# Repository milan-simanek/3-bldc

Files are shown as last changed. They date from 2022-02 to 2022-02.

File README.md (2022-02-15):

# 3-bldc
3-phase brushless DC motor controller

## Features:
- controls 3-phase BLDC motor
- synchronization using opto-sensors

## Arduino peripherals usage:
- Timer0 - PWM
- Timer1 - generic timer, phase detection
- PB0:5 - phase output
    - PB0: phase 1 - high
    - PB1: phase 2 - high
    - PB2: phase 3 - high
    - PB3: phase 1 - low
    - PB4: phase 2 - low
    - PB5: phase 3 - low
- PC0/PCINT8 - ~FAULT - overcurrent detection
- PC3/ADC3 - output current measurement
- PD0:1 - serial communication
- PD2/INT0 = (zero angle = home position) detection (triggered by both edges)
- PD3/INT1 = step sensor A
- PD4 = step sensor B
- PD5 = OC0B = PWM output

## Issues:
- opto-sensor feedback is currently amplified by operating amplifiers.
  Unfortunately, these devices should operate on higher voltage, so 
  amplification is not so stable and produces flicking.
  Solution: signal from opto-sensors should be amplified and
  conditioned by CMOS invertor based schmitt trigger.

## TODO:
- rotation feedback could be derived from back-EMF.
- maximum speed, acceleration measurements
- use avrm modules for usart communication and text formating (comf)

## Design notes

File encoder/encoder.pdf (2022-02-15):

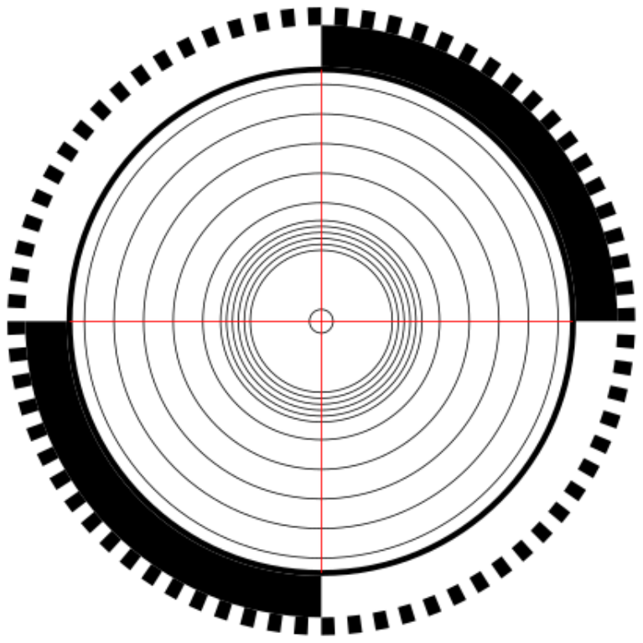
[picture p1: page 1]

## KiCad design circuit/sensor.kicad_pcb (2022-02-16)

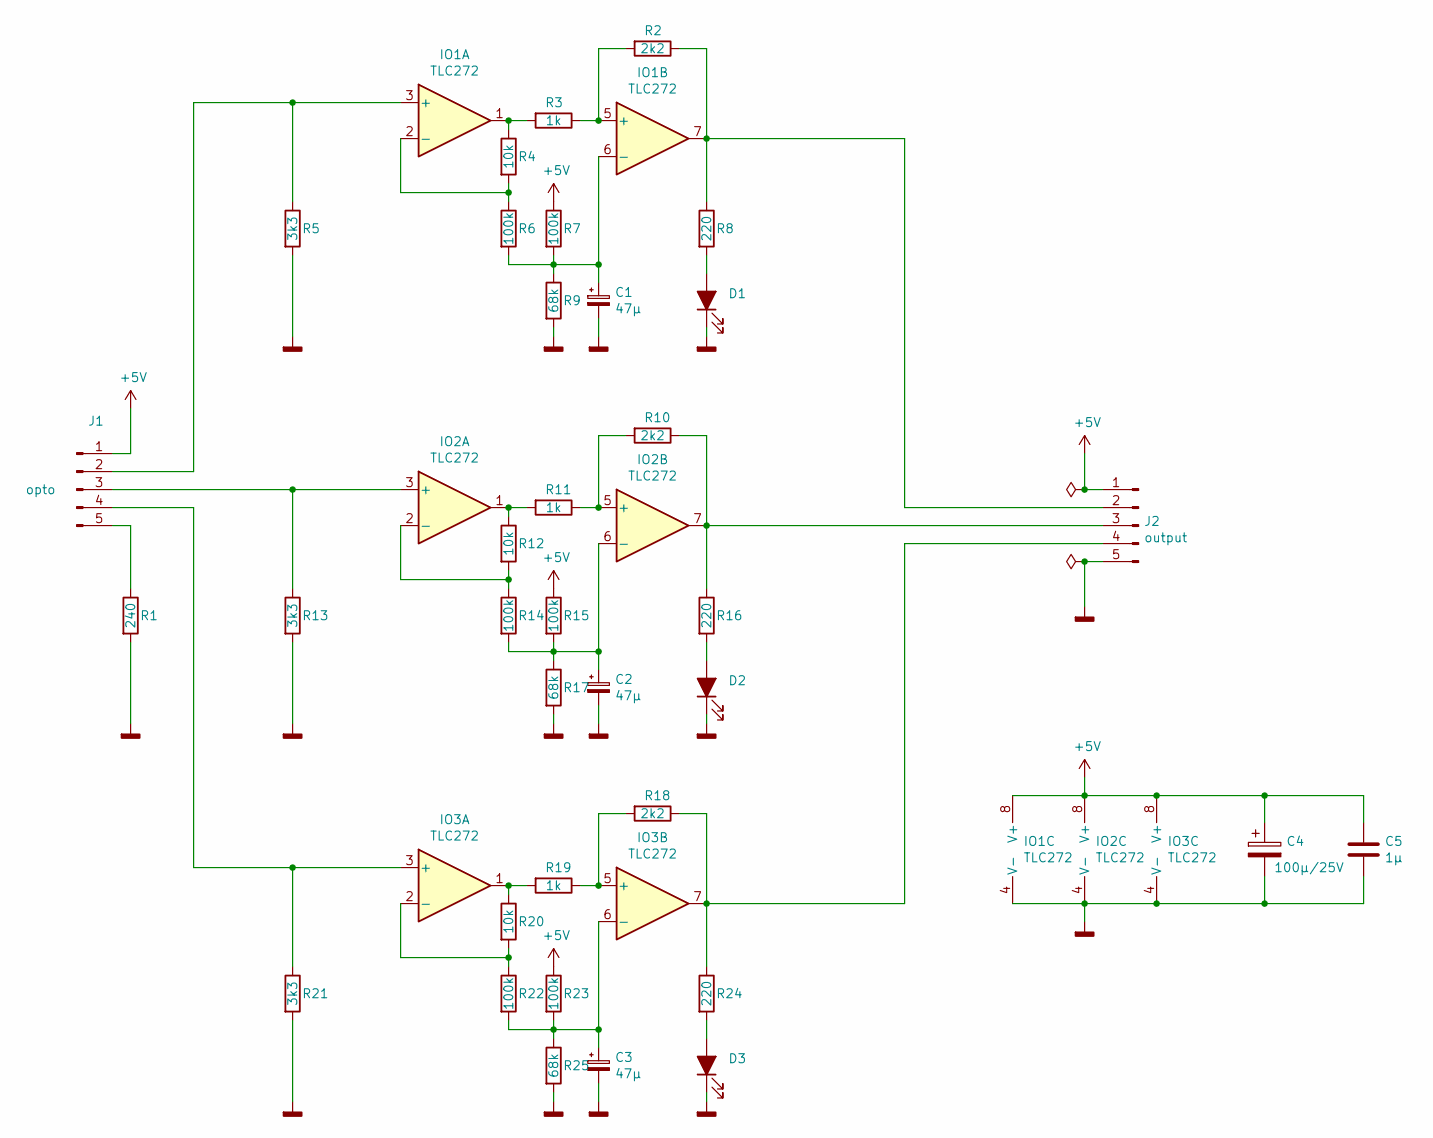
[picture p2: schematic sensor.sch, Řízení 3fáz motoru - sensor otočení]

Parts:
C1, C2, C3: 47μ; CP_Radial_D5.0mm_P2.50mm
C4: 100μ/25V; CP_Radial_D6.3mm_P2.50mm
C5: 1μ; C_Rect_L16.5mm_W4.7mm_P15.00mm_MKT
D1, D2, D3: LED_ALT; LED_D3.0mm
IO1, IO2, IO3: TLC272; DIP-8_W7.62mm_LongPads
J1: opto; PinHeader_1x05_P2.54mm_Vertical
J2: output; PinHeader_1x05_P2.54mm_Vertical
R1: 240; R_Axial_DIN0207_L6.3mm_D2.5mm_P10.16mm_Horizontal
R2, R10, R18: 2k2; R_Axial_DIN0207_L6.3mm_D2.5mm_P10.16mm_Horizontal
R3, R11, R19: 1k; R_Axial_DIN0207_L6.3mm_D2.5mm_P10.16mm_Horizontal
R4, R12, R20: 10k; R_Axial_DIN0207_L6.3mm_D2.5mm_P10.16mm_Horizontal
R5, R13, R21: 3k3; R_Axial_DIN0207_L6.3mm_D2.5mm_P10.16mm_Horizontal
R6, R7, R14, R15, R22, R23: 100k; R_Axial_DIN0207_L6.3mm_D2.5mm_P10.16mm_Horizontal
R8, R16, R24: 220; R_Axial_DIN0207_L6.3mm_D2.5mm_P10.16mm_Horizontal
R9, R17, R25: 68k; R_Axial_DIN0207_L6.3mm_D2.5mm_P10.16mm_Horizontal

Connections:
+5V: C4.1, C5.1, IO1.8 (V+), IO2.8 (V+), IO3.8 (V+), J1.1, J2.1, R7.1, R15.1, R23.1
GNDD: C1.2, C2.2, C3.2, C4.2, C5.2, D1.1 (K), D2.1 (K), D3.1 (K), IO1.4 (V-), IO2.4 (V-), IO3.4 (V-), J2.5, R1.2, R5.2, R9.2, R13.2, R17.2, R21.2, R25.2
unnamed: C1.1, IO1.6 (-), R6.2, R7.2, R9.1
unnamed: C2.1, IO2.6 (-), R14.2, R15.2, R17.1
unnamed: C3.1, IO3.6 (-), R22.2, R23.2, R25.1
unnamed: D1.2 (A), R8.2
unnamed: D2.2 (A), R16.2
unnamed: D3.2 (A), R24.2
unnamed: IO1.1, R3.2, R4.1
unnamed: IO1.2 (-), R4.2, R6.1
unnamed: IO1.3 (+), J1.2, R5.1
unnamed: IO1.5 (+), R2.2, R3.1
unnamed: IO1.7, J2.2, R2.1, R8.1
unnamed: IO2.1, R11.2, R12.1
unnamed: IO2.2 (-), R12.2, R14.1
unnamed: IO2.3 (+), J1.3, R13.1
unnamed: IO2.5 (+), R10.2, R11.1
unnamed: IO2.7, J2.3, R10.1, R16.1
unnamed: IO3.1, R19.2, R20.1
unnamed: IO3.2 (-), R20.2, R22.1
unnamed: IO3.3 (+), J1.4, R21.1
unnamed: IO3.5 (+), R18.2, R19.1
unnamed: IO3.7, J2.4, R18.1, R24.1
unnamed: J1.5, R1.1

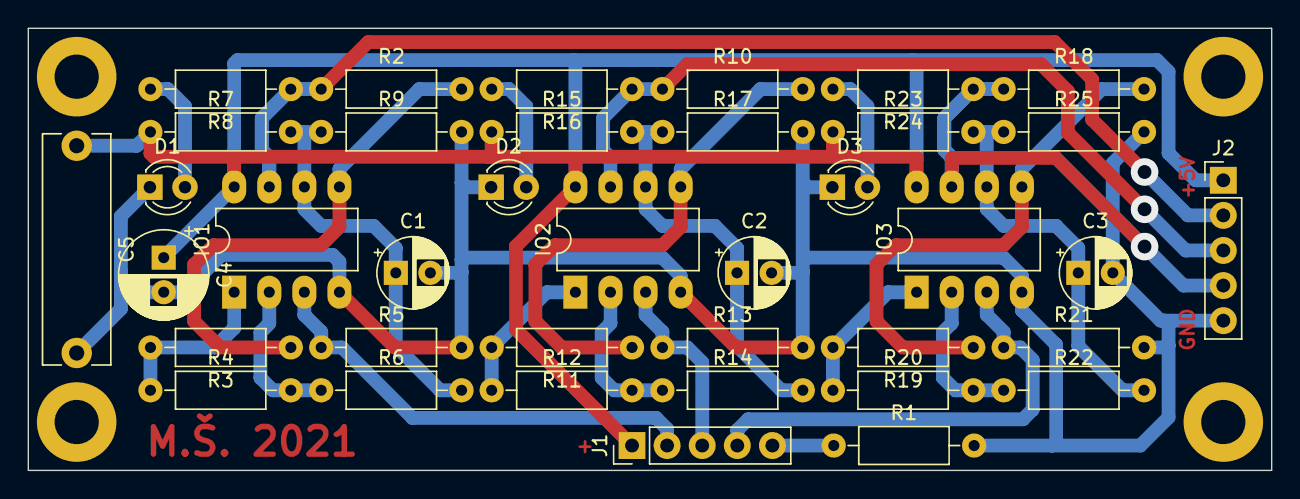
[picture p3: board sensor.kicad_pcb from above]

Board: 2 copper layers, 90.0 x 32.0 mm, 38 parts (0 on the bottom side), 24 nets.

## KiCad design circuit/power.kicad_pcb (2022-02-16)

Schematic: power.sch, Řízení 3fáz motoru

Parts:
C1: 15n; C_Rect_L4.6mm_W2.0mm_P2.50mm_MKS02_FKP02
C2, C4, C9: 330n; C213_L16_W7.5_P12.5
C3: 22μ; CP_Axial_L18.0mm_D6.5mm_P25.00mm_Horizontal
C5, C6, C7: 4μ7; CP_Radial_Tantal_D4.5mm_P2.50mm
C8: 1000μ/16V; CP_Radial_D10.0mm_P5.00mm
D1: error; LED_D5.0mm
D2, D3, D4, D5, D6, D7, D8, D9, D10: 1N4937; D_DO-41_SOD81_P10.16mm_Horizontal
IO1: CD4071; DIP-14_W7.62mm_LongPads
IO2: IR2130; DIP-28_W15.24mm_LongPads
J1: control; PinHeader_1x12_P2.54mm_Vertical
J2: test; PinHeader_1x06_P2.54mm_Vertical
J3: test; PinHeader_1x05_P2.54mm_Vertical
J4: power; BarrelJack_Horizontal
J5: power12; PinHeader_1x02_P2.54mm_Vertical
J6: motor; PinHeader_1x04_P2.54mm_Vertical
J7: msensor; PinHeader_1x04_P2.54mm_Vertical
P1: 680; Potentiometer_ACP_CA9-H5_Horizontal
P2: 220; Potentiometer_ACP_CA9-H5_Horizontal
R1, R2: 15k; R_Axial_DIN0207_L6.3mm_D2.5mm_P10.16mm_Horizontal
R3: 100k; R_Axial_DIN0207_L6.3mm_D2.5mm_P10.16mm_Horizontal
R4, R8: 1k; R_Axial_DIN0207_L6.3mm_D2.5mm_P10.16mm_Horizontal
R5: 10k; R_Axial_DIN0207_L6.3mm_D2.5mm_P10.16mm_Horizontal
R6: 0.5Ω/5W; R_Axial_Power_L25.0mm_W9.0mm_P30.48mm
R7: 220; R_Axial_DIN0207_L6.3mm_D2.5mm_P10.16mm_Horizontal
R9: 100; R_Axial_DIN0207_L6.3mm_D2.5mm_P10.16mm_Horizontal
R10, R11, R12, R13, R14, R15: 18; R_Axial_DIN0207_L6.3mm_D2.5mm_P10.16mm_Horizontal
T1: BSS83P; SOT-23
T2, T3, T4, T5, T6, T7: BUZ11; TO-220-3_Vertical
TL1: STOP; Tlacitko_hranate

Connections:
+5V: C2.1, C3.1, IO1.14, J1.2, R5.2, T1.3, TL1.2, TL1.3, TL1.5, TL1.6
+12V: C4.1, C8.1, C9.1, D5.1, D7.1, D9.1, IO2.1, J1.1, J4.1, J5.2, R9.1, T2.2, T4.2, T6.2
/CAO: IO2.10, J1.11, J3.3, R2.2, R3.2
/GNDPWR: C9.2, D6.2, D8.2, D10.2, IO2.13, R6.2, R8.1, T3.3, T5.3, T7.3
/L1: C5.2, D5.2, D6.1, IO2.26, J6.2, J7.2, T2.3, T3.2
/L2: C6.2, D7.2, D8.1, IO2.22, J6.3, J7.3, T4.3, T5.2
/L3: C7.2, D9.2, D10.1, IO2.18, J6.4, J7.4, T6.3, T7.2
/stop: C1.1, IO1.8, R1.2, TL1.1, TL1.4
/~FAULT: IO2.8, J1.10, J3.1, R5.1, T1.1
GNDD: C1.2, C2.2, C3.2, C4.2, C8.2, IO1.7, IO2.12, J1.12, J3.5, J4.2, J5.1, P1.3, P2.1, R1.1, R4.1, R6.1, R7.1
unnamed: C5.1, D2.1, IO2.28
unnamed: C6.1, D3.1, IO2.24
unnamed: C7.1, D4.1, IO2.20
unnamed: D1.1 (K), R7.2
unnamed: D1.2 (A), T1.2
unnamed: D2.2, D3.2, D4.2, R9.2
unnamed: IO1.1, J1.5
unnamed: IO1.3, IO2.3, J2.2
unnamed: IO1.4, IO2.4, J2.3
unnamed: IO1.6, J1.6
unnamed: IO1.9, J1.3
unnamed: IO1.2, IO1.5, IO1.10, IO1.12
unnamed: IO1.11, IO2.2, J2.1
unnamed: IO1.13, J1.4
unnamed: IO2.5, J1.7, J2.4
unnamed: IO2.6, J1.8, J2.5
unnamed: IO2.7, J1.9, J2.6
unnamed: IO2.9, J3.2, P2.2
unnamed: IO2.11, J3.4, P1.2, R3.1, R4.2
unnamed: IO2.14, R15.2
unnamed: IO2.15, R14.2
unnamed: IO2.16, R13.2
unnamed: IO2.19, R12.2
unnamed: IO2.23, R11.2
unnamed: IO2.27, R10.2
unnamed: J6.1, J7.1
unnamed: P1.1, R2.1
unnamed: P2.3, R8.2
unnamed: R10.1, T2.1
unnamed: R11.1, T4.1
unnamed: R12.1, T6.1
unnamed: R13.1, T3.1
unnamed: R14.1, T5.1
unnamed: R15.1, T7.1

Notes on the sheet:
12V DC

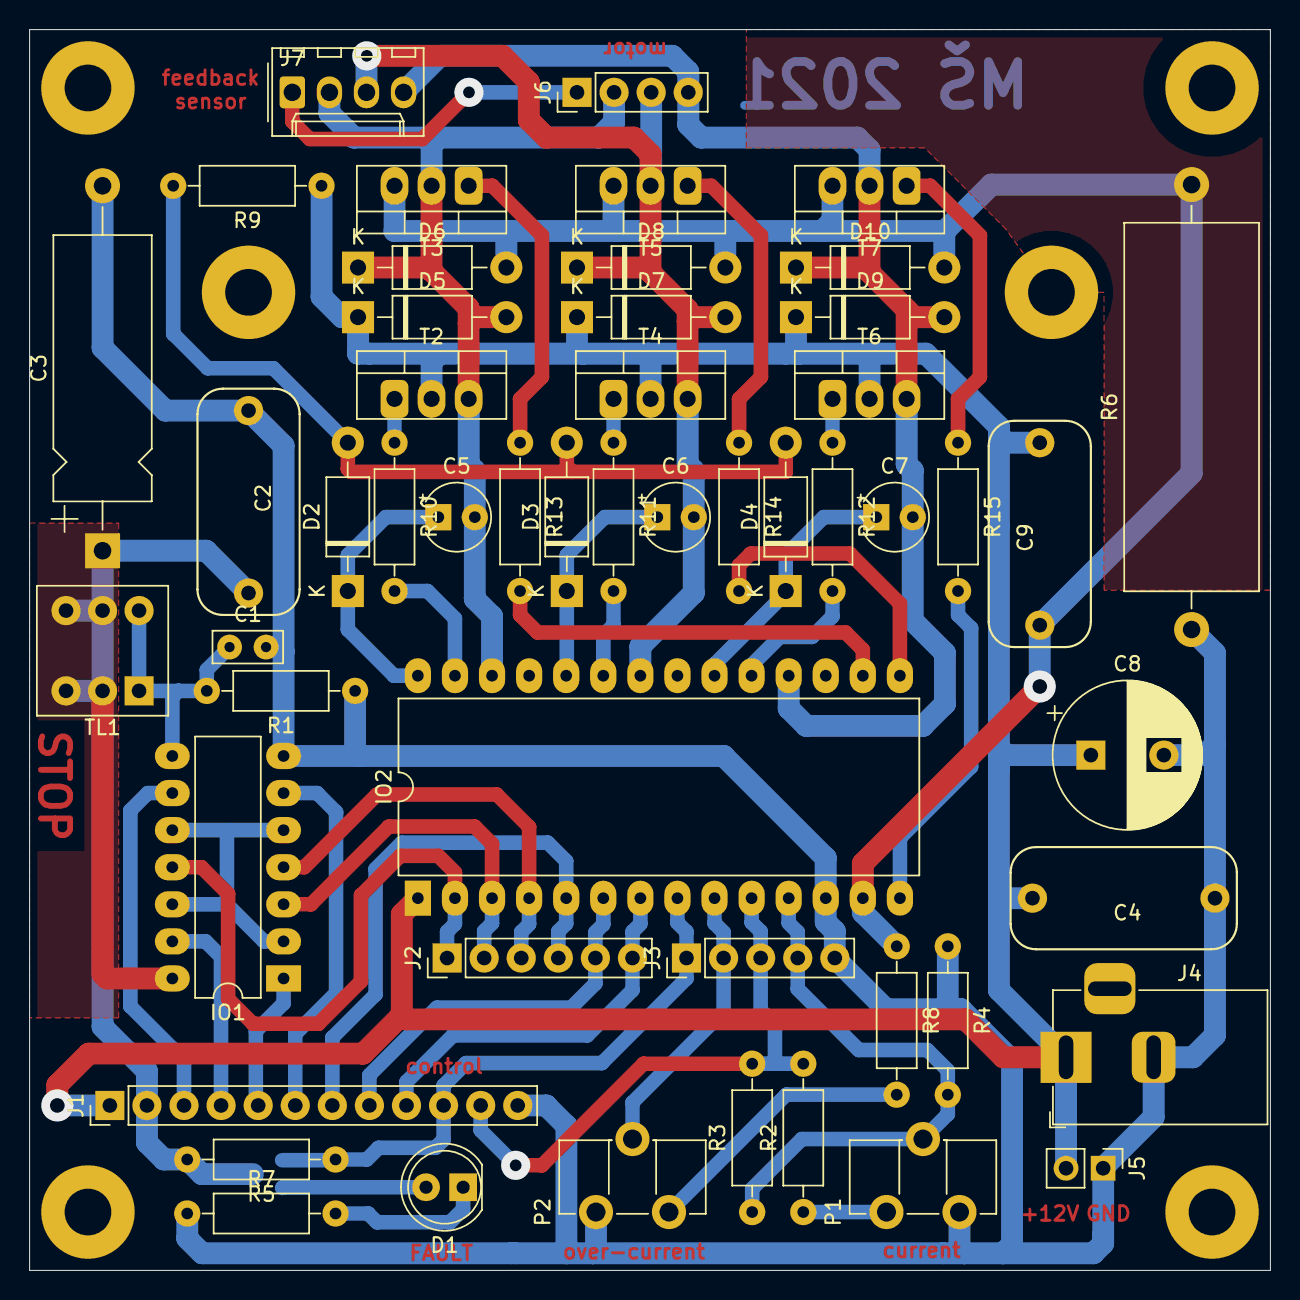
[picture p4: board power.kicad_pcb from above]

Board: 2 copper layers, 85.0 x 85.0 mm, 53 parts (1 on the bottom side), 44 nets.

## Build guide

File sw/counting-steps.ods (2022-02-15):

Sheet: steps36
SENSORSTEPS |  | 36
 |  | counting up |  | counting down
step | PosFrac8 | F(n+1)-F(n) | (F(n)+7)&0x3F==0x3F | F(n)-F(n-1) | F(n)&0x3F==0
0 | 0 | 7 | 0 |  | 1
1 | 7 | 7 | 0 | 7 | 0
2 | 14 | 7 | 0 | 7 | 0
3 | 21 | 7 | 0 | 7 | 0
4 | 28 | 7 | 0 | 7 | 0
5 | 35 | 7 | 0 | 7 | 0
6 | 42 | 7 | 0 | 7 | 0
7 | 49 | 7 | 0 | 7 | 0
8 | 56 | 8 | 1 | 7 | 0
9 | 64 | 7 | 0 | 8 | 1
10 | 71 | 7 | 0 | 7 | 0
11 | 78 | 7 | 0 | 7 | 0
12 | 85 | 7 | 0 | 7 | 0
13 | 92 | 7 | 0 | 7 | 0
14 | 99 | 7 | 0 | 7 | 0
15 | 106 | 7 | 0 | 7 | 0
16 | 113 | 7 | 0 | 7 | 0
17 | 120 | 8 | 1 | 7 | 0
18 | 128 | 7 | 0 | 8 | 1
19 | 135 | 7 | 0 | 7 | 0
20 | 142 | 7 | 0 | 7 | 0
21 | 149 | 7 | 0 | 7 | 0
22 | 156 | 7 | 0 | 7 | 0
23 | 163 | 7 | 0 | 7 | 0
24 | 170 | 7 | 0 | 7 | 0
25 | 177 | 7 | 0 | 7 | 0
26 | 184 | 8 | 1 | 7 | 0
27 | 192 | 7 | 0 | 8 | 1
28 | 199 | 7 | 0 | 7 | 0
29 | 206 | 7 | 0 | 7 | 0
30 | 213 | 7 | 0 | 7 | 0
31 | 220 | 7 | 0 | 7 | 0
32 | 227 | 7 | 0 | 7 | 0
33 | 234 | 7 | 0 | 7 | 0
34 | 241 | 7 | 0 | 7 | 0
35 | 248 | 8 | 1 | 7 | 0
 | 256 |  |  | 8 | 1
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

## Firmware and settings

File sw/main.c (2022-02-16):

#include "globals.h"
#include <avr/io.h>
#include <avr/interrupt.h>
#include <avr/sleep.h>
#include <avr/pgmspace.h>
#include "main.h"
#include "libclk.h"
#include "passive-wait.h"
#include "com.h"
#include "proto.h"
#include "pwm.h"
#include "const.h"
#include "rot.h"
#include "sensor.h" 
#include "tick.h"
#include "ledkey.h"
#include "ports.h"
#include "macro_ports.h"
#include "usart.h"
#include "comf.h"

char dbgf=1; // debug flag


/**********************************************/

#define MS_OTACEK	6
const char M_MS0[]	PROGMEM = "Measure: \r";
const char M_MS1[]	PROGMEM = "MS: motor off\r";
const char M_MS2[]	PROGMEM = "MS: go to angle 0\r";
const char M_MS_S[]	PROGMEM = "MS: initialization round phase=%\r";
const char M_MS_M[]	PROGMEM = "MS: ph=% pos=% ph-pos=% total=% t_val=%\r";
const char M_MS_E[]	PROGMEM = "MS: end. Sensor=%\r";

// measures the location of zero_angle sensor
unsigned ms_timer;
void MeasureSensor(void) {
  ComFormat(M_MS0);
  SensorDetecting=1;
  ms_timer=3 MST_SECOND;
}
uchar NextPhasePF8(uchar pf8) {
  for(unsigned i=PHASESTEPS;i--;) { StepPlus(pf8); }
  return pf8;
}
  
void MeasureSensorNext(void) {
  static uchar ph;
  static unsigned t_val;
  static int16_t result;
  static uchar curPF8;
  uchar x;
  switch (SensorDetecting++) {
  case 1:			// stop motor
    ComFormat(M_MS1);
    result=0;
    SensorOffset8=0;
    StopMotor();
    ms_timer=1 MST_SECOND;
    break;
  case 2:			// rotate to phase 0 0
    ComFormat(M_MS2);
    OutPhase(ph=0); curPF8=0;
    SetPWM(64);
    ms_timer=1 MST_SECOND;
    break;
  case 3: case 4: case 5: case 6: case 7: case 8: // rotate one round to trigger the sensor
    if (++ph>5) ph=0; 
    curPF8=NextPhasePF8(curPF8);
    OutPhase(ph);
    ComFormat(M_MS_S); ComFHex2(ph);
    ms_timer=10 MST_100MS;
    t_val=10 MST_100MS;
    break;
//  case 9-26: 			// angle measurement
  case MS_OTACEK*6+9:		// finish measurement
    StopMotor();
    result/=(MS_OTACEK*6);
    while (result>0) {		// SensorOffset8=-result;
      StepMinus(result);
      StepMinus(SensorOffset8);
    }
    ComFormat(M_MS_E); ComFHex4(SensorOffset8);
    SensorDetecting=0;
    SetPWM(0);
    break;    
  default: 			// measure each step
    x=PosFract8-curPF8;
    result+=x;
    ComFormat(M_MS_M); ComFHex2(ph); ComFHex2(PosFract8); ComFHex2(x); ComFHex4(result); ComFHex4(t_val);
    ms_timer=t_val;
    t_val-=t_val>>4; 		// speed up
    if (++ph>5) ph=0; 
    curPF8=NextPhasePF8(curPF8);
    OutPhase(ph);
  }
}

void TimeTick(void) {
  static uchar report;
  if (SensorDetecting) if (!--ms_timer) MeasureSensorNext();
  if (!SensorDetecting && (dbgf&1) && !--report) {
    Report();
    report=3 MST_100MS;
  }
}

const char M_Ready[]          PROGMEM = "=== READY ===\r";

int main(void) {
  InitCLK();
  PortsInit();
  LedkeyInit();  
  MotorOFF();
  UsartInit();
  sleepms(100);
  InitTick();
  InitPWM();
  InitRot();
  InitFault();
  InitSensor();
  sei();
  ComFormat(M_Ready);
  Fault=1;
  for(;;) {
//    LedAll(Key());
    LedkeyPrintHex(Rot,0,4,LKF_DOT);
    SleepOnAction();
    if (TestAction(ACT_COM)) ProtoReceive();
    if (TestAction(ACT_TICK)) TimeTick();
  }
}

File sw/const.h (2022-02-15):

#ifndef _CONST_H_
#define _CONST_H_

#include "globals.h"



#define MINRPM 60*1
#define MAXRPM 4000

// T1 = calculation of derivatives
// T1: CS:PRESCALER  1:1 2:8 3:64 4:256 5:1024
//#define T1_TOP		15999
//#define T1_CS		1
#define T1_DIV		15625
#define T1_CS		2
#define T1_PRESCALER	8
#define T1_CLKF		(F_CPU/T1_PRESCALER)	// 16MHz
#define T1_FREQ		(T1_CLKF/(T1_DIV))	// 1kHz
#define T1_TOP		(T1_DIV-1)
// T2 = independent timer
#define T2_DIV		125
#define T2_PRESCALER	1024
#define T2_CLKF		(F_CPU/T2_PRESCALER)	// 15625 [Hz]
#define T2_FREQ		(T2_CLKF/(T2_TOP+1))	// interrupt frequency 125 [Hz]
#define T2_TOP		(T2_DIV-1)
#define F_TICK		T2_FREQ
#define MST_SECOND	*T2_FREQ
#define MST_100MS	*(T2_FREQ/10)


#endif

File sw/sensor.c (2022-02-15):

#include <stdint.h>
#include <avr/io.h>
#include <avr/interrupt.h>
#include "const.h"
#include "sensor.h"
#include "main.h"
#include "rot.h"
#include "com.h"
#include "ports.h"
#include "macro_ports.h"

#define DEFAULT_SENSOROFFSET8	0xE0

uchar SensorOffset8, SensorDetecting;
uchar PosFract8, PosRots;
uchar d2;

/************* Phase Control **************/
// PB0=~H1 PB1=~H2 PB2=~H3 PB3=~L1 PB4=~L2 PB5=~L3 (111111b=0x3F=off state)
//
//                               LLLHHH
//                               321321
const uint8_t CommuteMAP[] = { 0b101110,
                               0b011110,
                               0b011101,
                               0b110101,
                               0b110011,
                               0b101011,
                               0,0 };

void OutPhase(uchar phase) {
  while (phase>5) phase-=6;
  MPORT(PHASES)=(MPORT(PHASES) & ~MMASK(PHASES)) | CommuteMAP[phase];
}

void Commute(void) {
  uchar register phase;
  if (SensorDetecting) return;
  if (Fault || !MotorAction) { MotorOFF(); return; };
  phase=PosFract8;
  phase+=MotorAction;
  phase=(phase*6+128)>>8; if (phase==6) phase=0;
  OutPhase(phase);
}
void MotorOFF(void) {		// disconnect motor
  MPORT(PHASES)|=0b111111;
}
void MotorLOW(void) {		// breaks
  MotorOFF();
  MPORT(PHASES)&=~0b111000;
}

#ifndef ASM_INT1

ISR(INT1_vect) {		// step PD3=STEPA + PD4=STEPB
  register uchar x;
  x=PIN(STEPA)+PMASK(STEPA);
  if (x&PMASK(STEPB)) {		// bits differ
    StepPlus(PosFract8);
    if (!PosFract8) PosRots++;
  } else {			// bits are equal
    if (!PosFract8) PosRots--;
    StepMinus(PosFract8);
  }
  Commute();
} 

#endif

#ifndef ASM_INT0
ISR(INT0_vect) {		// reached home position = 0 angle
  d2=PosFract8;
  if (PosFract8>0x80+SensorOffset8) PosRots++;		// offset with overflow
  else if (PosFract8+0x80<SensorOffset8) PosRots--;	// offset with underflow
  PosFract8=SensorOffset8; 				// offset = syncing
}
#endif

void InitSensor(void) {
  PosFract8=0;
  SensorOffset8=DEFAULT_SENSOROFFSET8;
  EICRA=(1<<ISC00)|(1<<ISC10);	// any change in INT0,INT1 triggers an interrupt
  EIMSK=(1<<INT0)|(1<<INT1);	// enable INT0+INT1
}

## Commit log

2022-02-15 initial implementation
    [calculations.ods, counting-steps.ods, fuse.cfg]
2022-02-16 add module: ledkey
2022-02-16 add schematics
    [arduino-board.kicad_pcb, cables.sch, power.kicad_pcb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]
